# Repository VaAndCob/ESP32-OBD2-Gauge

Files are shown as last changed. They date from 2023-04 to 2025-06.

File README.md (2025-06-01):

# ESP32-OBD2-Gauge
A fully functional code-updated
Last Update: September 27th, 2024

This is an ESP32 OBD2 Gauge for vehicles that are compatible with obd2
(Special made for FORD vehicle)
 - Prototype https://youtu.be/PkQaUJbzTNM
 - Current Model Short Demo https://youtu.be/vvBIeim7XTE
   
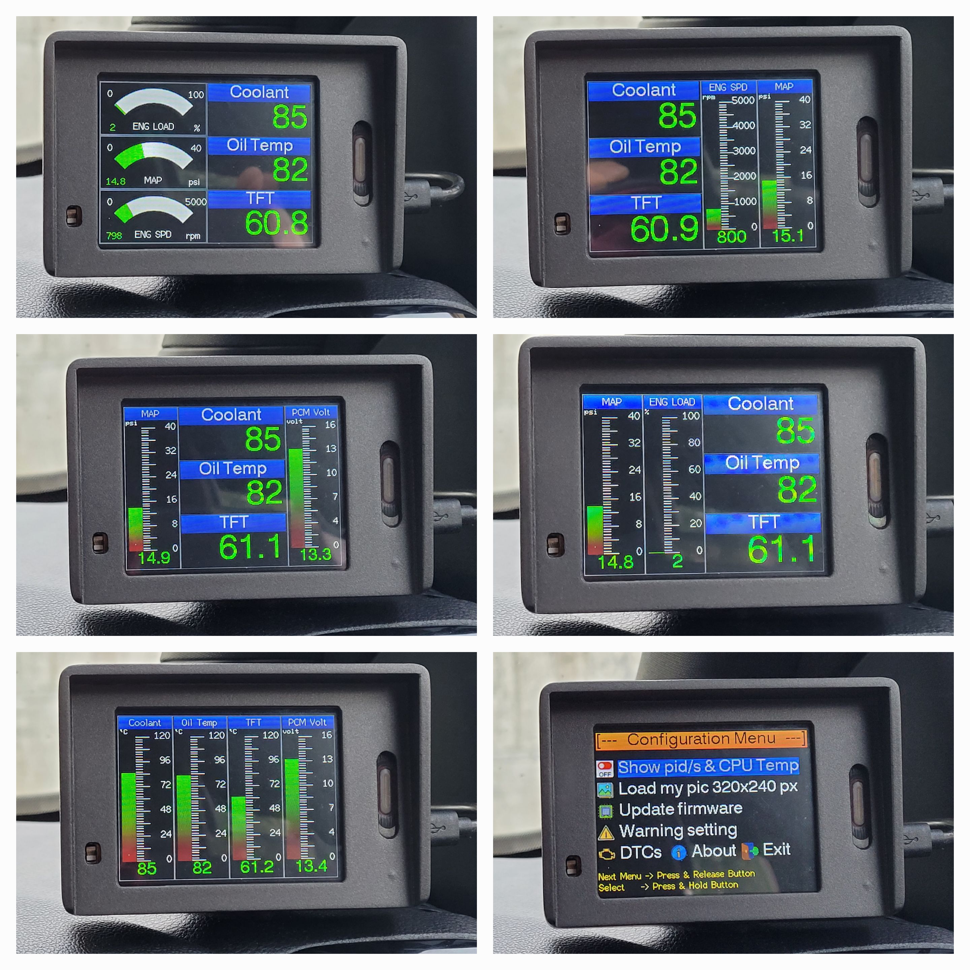
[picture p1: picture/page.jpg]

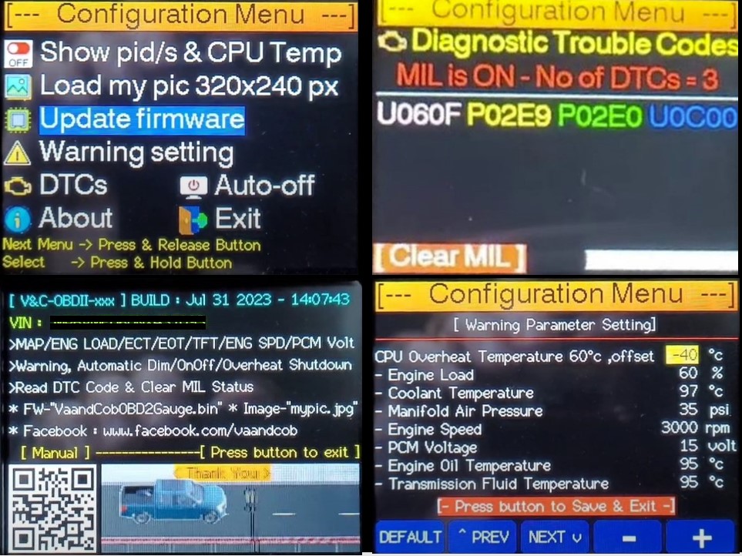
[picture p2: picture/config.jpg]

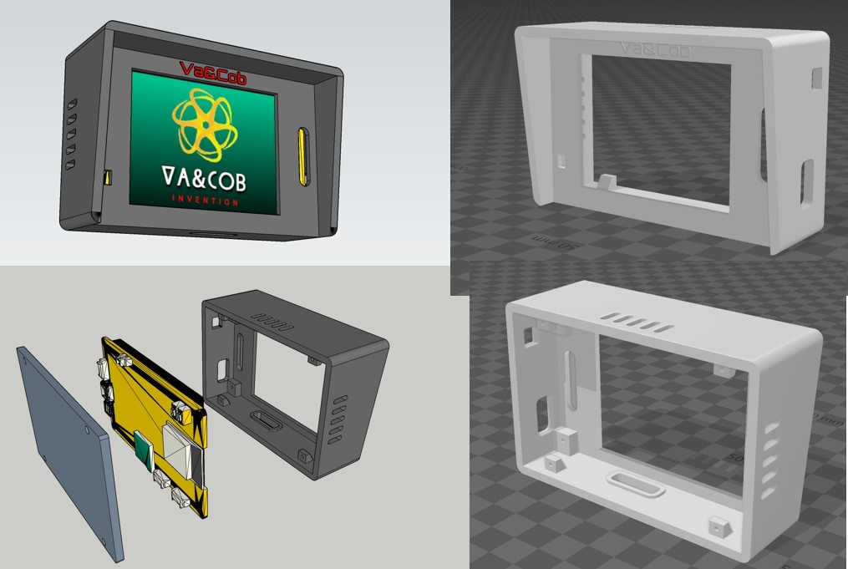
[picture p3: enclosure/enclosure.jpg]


## Software:
- Arduino IDE 2.3.2 + ESP32 arduino core 2.0.17
- * IMPORTANT * this project won't work with ESP32 arduiino core 3.x.x
- modified TFT_eSPI library 2.5.43

## Hardware
- ESP32 TFT2.8 320x240 with "RESISTIVE" touch board.
buy here  https://s.click.aliexpress.com/e/_Ew95gMl 
- ELM327 Bluetooth adaptor (recommended v1.5 not v2.1)
  Highly recommend ELM327 Bluetooth  adaptor https://s.click.aliexpress.com/e/_oo3THvG
- A small speaker for mobile phone 1 Watt 8 ohm 9x28 mmm.
- A push button 6x6x5 2 legs
- 3d print enclosure
- 12v to 5v dc micro usb power regulator module
- Gauge magnetic stand

## Features:
- Show vehicle data 7 pids
* MAP - manifold air pressure (PSI)
* PCM - pcm voltage (volt)
* ENG LOAD - engine load (%)
* ENG SPD - engine speed (RPM)
* Coolant - coolant temperature (c)
* Oil Temp - engine oil temperature (c)
* TFT - Ford transmission fluid temperature (c)

- 8 layout page selectable display
- DTC read and clear function (Engine warning light only)
- Warning when parameter reaches setting value
- Adjustable warning value for each PIDs
- Configurable CPU overheat protection
- Configurable gauge Auto turn on/off
- Auto screen brightness
- Change off screen to user screen with micro SDcard
- Firmware updatable (micro SDcard and WiFi)
- VIN Read on the About page.

## [Flash Firmware Online](https://vaandcob.github.io/webpage/src/index.html)

-------------------------------------------------------
Buy Me a Coffee (https://www.buymeacoffee.com/vaandcob)

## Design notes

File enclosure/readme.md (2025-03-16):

3d print files



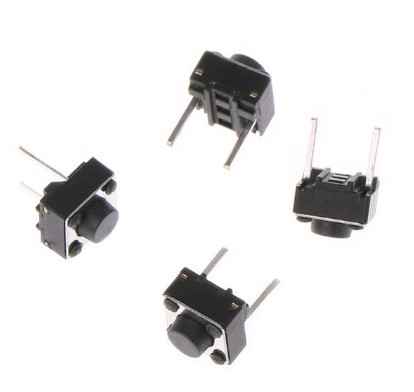
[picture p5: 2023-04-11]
hardware/push_button.jpg

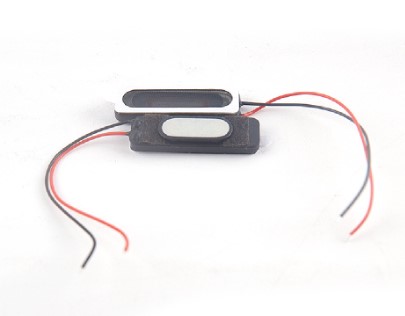
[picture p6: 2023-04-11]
hardware/speaker.jpg

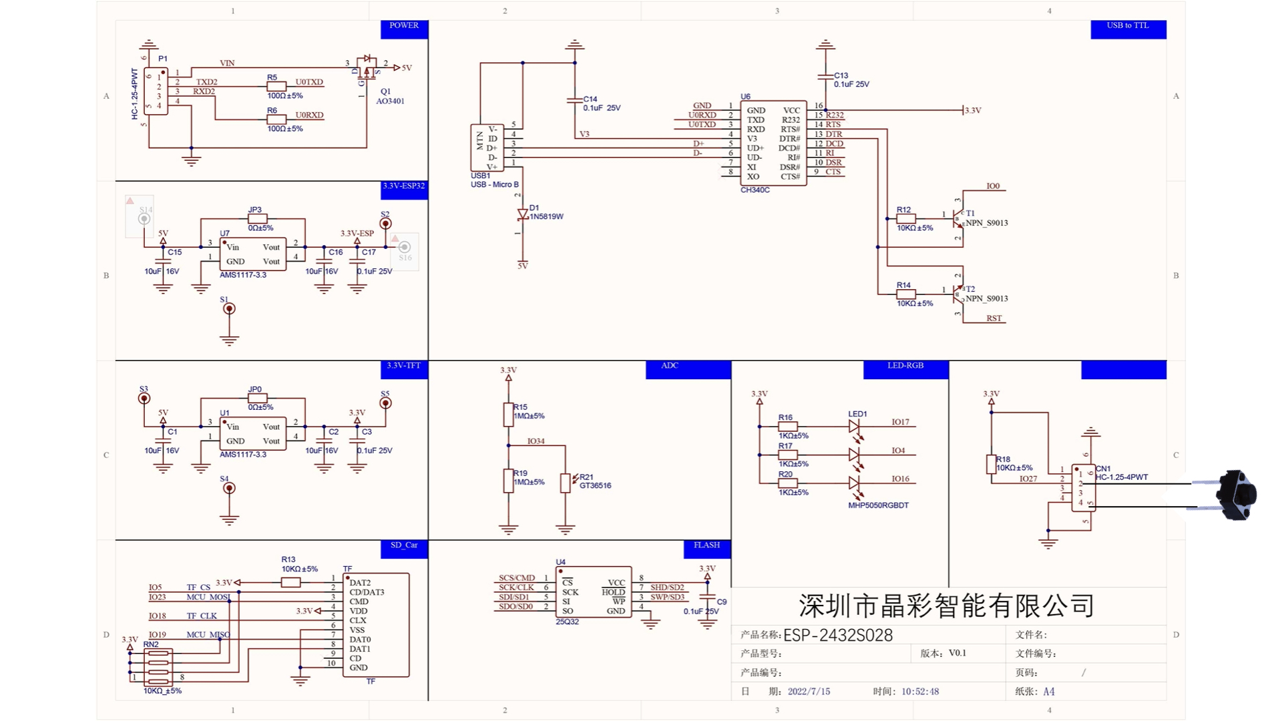
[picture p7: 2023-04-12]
hardware/ESP32-2432S028-LCM002.jpeg

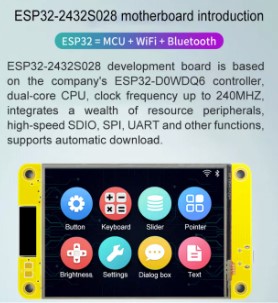
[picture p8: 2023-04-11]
hardware/ESP32 lvgl_touch.jpg

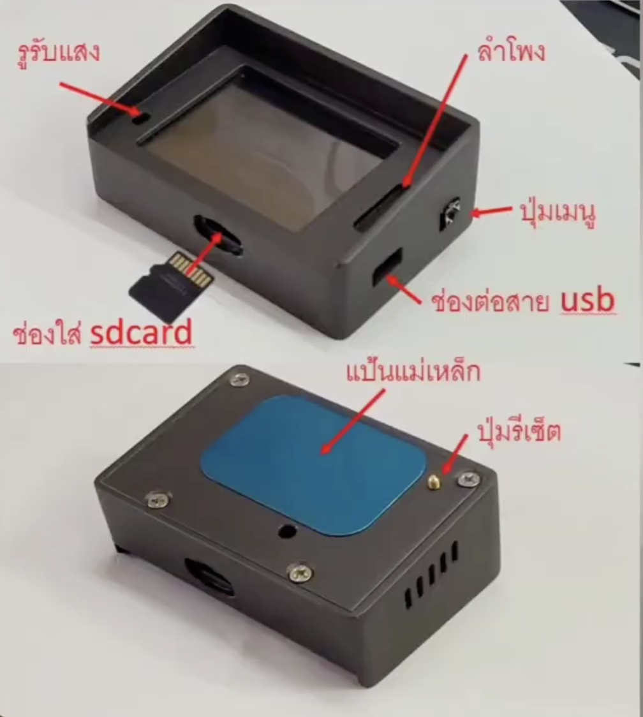
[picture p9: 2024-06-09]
hardware/Box.png

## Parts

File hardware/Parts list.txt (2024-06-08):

ESP32 Arduino LVGL WIFI&Bluetooth Development Board 2.8" 240*320 Smart Display Screen 2.8inch LCD TFT Module With Touch WROOM
https://s.click.aliexpress.com/e/_DB8Ht8N

Micro USB Output 12V to 5V 3A 
https://shopee.co.th/%E2%98%80S%E2%98%80%E0%B8%AD%E0%B8%B8%E0%B8%9B%E0%B8%81%E0%B8%A3%E0%B8%93%E0%B9%8C%E0%B9%81%E0%B8%9B%E0%B8%A5%E0%B8%87%E0%B8%9E%E0%B8%B2%E0%B8%A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

ELM327 Bluetooth
https://s.click.aliexpress.com/e/_oo3THvG

Speaker 1W 8R 2809 8ohm
https://shopee.co.th/(Takashitree)-%E0%B8%A5%E0%B9%8D%E0%B8%B2%E0%B9%82%E0%B8%9E%E0%B8%87%E0%B8%AE%E0%B8%AD%E0%B8%A3%E0%B9%8C%E0%B8%99%E0%B8%84%E0%B8%AD%E0%B8%A1%E0%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

Push button
Push Bottom Switch  6x6x5 mm

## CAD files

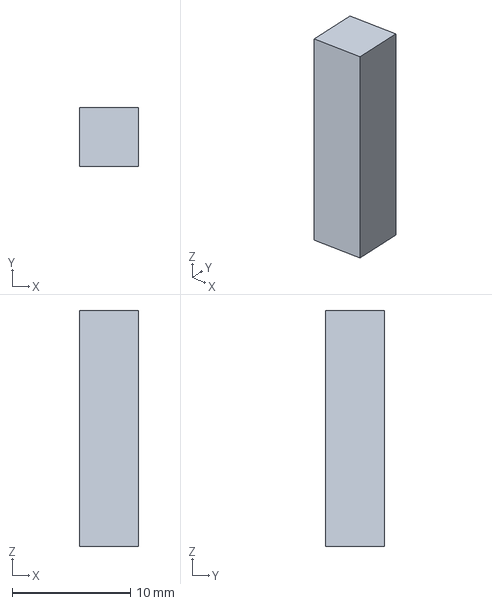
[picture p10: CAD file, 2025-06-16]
enclosure/Va&CobGauge.3mf
5.00 x 5.00 x 20.0 mm

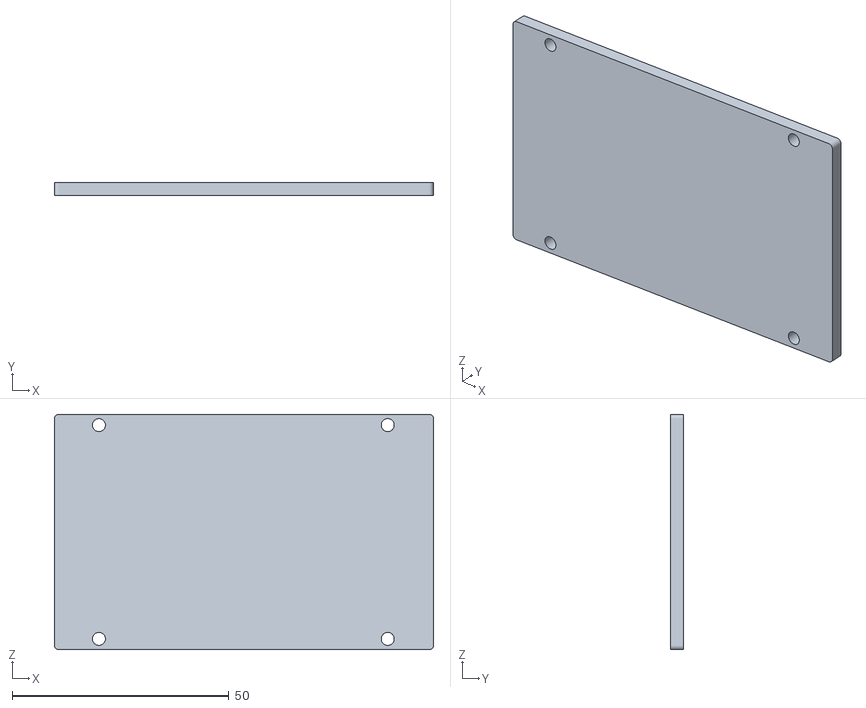
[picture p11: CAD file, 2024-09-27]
enclosure/backcover.stl
87.4 x 3.00 x 54.3

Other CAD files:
enclosure/Va&CobGauge.gcode.3mf
enclosure/Va&CobGauge.skp
enclosure/Va&CobGauge.stl

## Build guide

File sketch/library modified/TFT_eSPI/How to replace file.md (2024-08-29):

TFT_eSPI release 2.5.43

Explore to 
- C:\...\Arduino\Sketch\libraries\TFT_eSPI
- backup User_Setup.h file by rename to User_Setup_ORG.h
- copy new User_Setup.h to TFT_eSPI folder

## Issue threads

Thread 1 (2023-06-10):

Instructions how to use

nomidaepapi, 2023-06-10:
Hello. Im tryping to make a OBD2 project with my Lexus GS300 2001 with a ESP32 and ELM327 bluetooth adapter 2.1. I want to use your lib to connect to the ELM327 and retrieve RPM values; but which code do i use exactly to do this?

VaAndCob, 2023-06-11:
In the sketch. There are 4-5 sketches that run together for this project.
In case you want to read rpm or etc..
It's all about interpretation with elm327.
I suggest you read more info about elm327 at command.
Or you can simply try elm327 bluetooth with Bluetooth terminal app and see how it responds.
If possible, i suggest you test your elm327 2.1 via obd2 app on store and see if your adapter is really compatible or works with your lexus car

Closed 2024-05-09.

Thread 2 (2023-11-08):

Incompatibility with BluetoothSerial library on LilyGo T-Display-S3

Talha-Babar, 2023-11-08:
i am working on similar project and when i attempting to use the BluetoothSerial library with the LilyGo T-Display-S3 board results in compilation errors. The same code compiles and runs as expected on a standard ESP32 board, indicating the issue is specific to the LilyGo T-Display-S3 board.

Here is the code:

#include "BluetoothSerial.h"

BluetoothSerial SerialBT; // Object for Bluetooth

void setup() {
Serial.begin(115200); // Start the built-in serial port, possibly to communicate with the host computer
//SerialBT.begin("ESP32test"); // Start BluetoothSerial with the name "ESP32test"

Serial.println("Bluetooth device is ready to pair");
}

void loop() {
if (SerialBT.available()) { // Check if we receive anything from Bluetooth
Serial.write(SerialBT.read()); // Send what we receive to the built-in serial port
}

if (Serial.available()) { // Check if anything is coming from the built-in serial port
SerialBT.write(Serial.read()); // Send what we receive to Bluetooth
}
}

Here is the error:

c:/users/talha/appdata/local/arduino15/packages/esp32/tools/xtensa-esp32s3-elf-gcc/esp-2021r2-patch5-8.4.0/bin/../lib/gcc/xtensa-esp32s3-elf/8.4.0/../../../../xtensa-esp32s3-elf/bin/ld.exe: libraries\BluetoothSerial\BluetoothSerial.cpp.o:(.literal._ZL8_stop_btv+0x18): undefined reference to esp_spp_disconnect' c:/users/talha/appdata/local/arduino15/packages/esp32/tools/xtensa-esp32s3-elf-gcc/esp-2021r2-patch5-8.4.0/bin/../lib/gcc/xtensa-esp32s3-elf/8.4.0/../../../../xtensa-esp32s3-elf/bin/ld.exe: libraries\BluetoothSerial\BluetoothSerial.cpp.o:(.literal._ZL8_stop_btv+0x1c): undefined reference to esp_spp_deinit'
c:/users/talha/appdata/local/arduino15/packages/esp32/tools/xtensa-esp32s3-elf-gcc/esp-2021r2-patch5-8.4.0/bin/../lib/gcc/xtensa-esp32s3-elf/8.4.0/../../../../xtensa-esp32s3-elf/bin/ld.exe: libraries\BluetoothSerial\BluetoothSerial.cpp.o: in function _stop_bt()': C:\Users\Talha\AppData\Local\Arduino15\packages\esp32\hardware\esp32\2.0.14\libraries\BluetoothSerial\src/BluetoothSerial.cpp:714: undefined reference to esp_spp_disconnect'
c:/users/talha/appdata/local/arduino15/packages/esp32/tools/xtensa-esp32s3-elf-gcc/esp-2021r2-patch5-8.4.0/bin/../lib/gcc/xtensa-esp32s3-elf/8.4.0/../../../../xtensa-esp32s3-elf/bin/ld.exe: C:\Users\Talha\AppData\Local\Arduino15\packages\esp32\hardware\esp32\2.0.14\libraries\BluetoothSerial\src/BluetoothSerial.cpp:715: undefined reference to `esp_spp_deinit'
collect2.exe: error: ld returned 1 exit status
exit status 1
Error compiling for board LilyGo T-Display-S3.

VaAndCob, 2023-11-09:
my sketch used the esp32 core library,  [BluetoothSerial.h](https://github.com/espressif/arduino-esp32/tree/master/libraries/BluetoothSerial)
Not the library from external source
or if you use arduino-esp32 BluetoothSerial.h   ,  perhaps it doesn't update and not compatible with Lilygi ESP32 S3,
but you can edit this library.  Those errors are  "undefined references"

Closed 2024-05-09.

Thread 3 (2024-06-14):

i dont have the yellow display..but i have the 2.4inch spi interface display..

rohanjoshy2005, 2024-06-14:
i dont have the yellow display..but i have the 2.4inch spi interface display...is this display compaitable with this project and can you give me the wiring digram

VaAndCob, 2024-06-16:
This module tft screen use SPI as well. For the schematic diagram, it's in hardware folder.

VaAndCob, 2024-06-16:
This module tft screen use SPI as well. For the schematic diagram, it's in hardware folder.

rohanjoshy2005, 2024-06-16:
and i have the basic version of obd2..ELM327 mini...is it possible to do with it

VaAndCob, 2024-08-02:
> and i have the basic version of obd2..ELM327 mini...is it possible to do with it

you can try, nobody can say, but I recommend original ELM327 with pic chip.

rohanjoshy2005, 2024-08-04:
can you please give me the pinout for each components(not like diagram)like
vcc-3v,gnd-gnd like that

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

VaAndCob, 2024-08-05:
> can you please give me the pinout for each components(not like diagram)like vcc-3v,gnd-gnd like that
> […](#)

you can google ESP32 and TFT 2.4" SPI example , connection, diagram and example code.

Closed 2024-10-09.

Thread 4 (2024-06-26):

Question: Enclosure design files

aguedob, 2024-06-26:
First of all, congrats for such a great project! I have one question for you. I really like the enclosure shown in your photos. Is 3d printed? Do you have the design files? Thank you!

mateusleom, 2024-09-20:
[Case Esp32.zip](https://github.com/user-attachments/files/17074926/Case.Esp32.zip)
I made this myself, its similar to the one shown in the developer pictures

VaAndCob, 2024-09-27:
> [Case Esp32.zip](https://github.com/user-attachments/files/17074926/Case.Esp32.zip) I made this myself, its similar to the one shown in the developer pictures

thank you mateusteom. very appreciated

VaAndCob, 2024-09-27:
> First of all, congrats for such a great project! I have one question for you. I really like the enclosure shown in your photos. Is 3d printed? Do you have the design files? Thank you!

I upload 3d print file for this enclosure, you can see it in 'enclosure folder'

Closed 2024-10-09.

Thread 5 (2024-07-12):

Please elaborate on "New device must flash "gauge_factory_init.ino" first to get it work by checking 'serialno' in pref."

rlagerweij, 2024-07-12:
I'm trying to flash your project to my new device. It is identical to the one you linked to. After building and flashing i just get a black screen and the text "Touch screen calibration..." on the serial monitor.

You mention in the notes: "New device must flash "gauge_factory_init.ino" first to get it work by checking 'serialno' in pref."

Is this related to the issue I am having?

I do not see this particular file in the source tree and google cant find it either.
Could you explain where I can find this file and what it does to the board to prepare it for you firmware?

Many thanks

VaAndCob, 2024-07-15:
you can skip this part in vaandcobobd2gauge.ino

remove guine check line. to skip checking.

ในวันที่ ศ. 12 ก.ค. 2024 เวลา 22:30 rlagerweij ***@***.***>
เขียนว่า:

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

--

*:•°ღ ♡♥♡♥♡♥♡♥♡ ღ*:•°*:•°ღ ♡♥♡♥♡♥♡♥♡ ღ*:•°

ks00x, 2024-07-16:
> I'm trying to flash your project to my new device. It is identical to the one you linked to. After building and flashing i just get a black screen and the text "Touch screen calibration..." on the serial monitor.

What you are seeing is the touchscreen calibration screen which only comes up the first time after the flash was erased. You need to click the 4 corners following the arrows and then the cal data is saved to flash. I have the thing running now but it is not connecting to my ODB adapters. I guess it needs the mac addr or id string first to work and maybe this is what the gauge_factory_init.ino is supposed to do...

rlagerweij, 2024-07-16:
The problem was that the screen remained off during the calibration stage.

I got it working by first applying the user_config.h to the eSPI_TFT library and then loading the device with an example from the library. After that i removed the calibration step from Setup() and then the logo showed up.

Can't really say what exactly fixed it.

VaAndCob, 2024-08-02:
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

example from TFT_espi might not work with this board. that's why I build 'touch.h' to use with this board.
Can u try compile sketch and run.  or if you could flash binary file to your board. (I have provided binary file)

Closed 2024-10-09.

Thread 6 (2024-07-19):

error: 'sigmaDeltaSetup' was not declared in this scope

amirzohaib, 2024-07-19:
error: 'sigmaDeltaSetup' was not declared in this scope

in the nes_audio.cpp. maybe its a library i need to install?

amirzohaib, 2024-07-19:
C:\Users\c9002481\Documents\Platform IO\ESP32-OBD2-Gauge-main\nes_audio.cpp: In member function 'void Cartridge::init()':
C:\Users\c9002481\Documents\Platform IO\ESP32-OBD2-Gauge-main\nes_audio.cpp:17:3: error: 'sigmaDeltaSetup' was not declared in this scope; did you mean 'sigmaDeltaDetach'?
   17 |   sigmaDeltaSetup(p1_pin, p1_channel, 88200);
      |   ^~~~~~~~~~~~~~~
      |   sigmaDeltaDetach
In file included from C:\Users\c9002481\Documents\Platform IO\ESP32-OBD2-Gauge-main\ESP32-OBD2-Gauge-main.ino:258:
C:\Users\c9002481\Documents\Platform IO\ESP32-OBD2-Gauge-main\config.h: In function 'void TaskPlayMusic(void*)':
C:\Users\c9002481\Documents\Platform IO\ESP32-OBD2-Gauge-main\config.h:58:21: error: invalid conversion from 'int' to 'const esp_task_wdt_config_t*' [-fpermissive]
   58 |   esp_task_wdt_init(62, false);//62 sec wd timer / disable wd
      |                     ^~
      |                     |
      |                     int
C:\Users\c9002481\Documents\Platform IO\ESP32-OBD2-Gauge-main\config.h:58:20: error: too many arguments to function 'esp_err_t esp_task_wdt_init(const esp_task_wdt_config_t*)'
   58 |   esp_task_wdt_init(62, false);//62 sec wd timer / disable wd
      |   ~~~~~~~~~~~~~~~~~^~~~~~~~~~~
In file included from C:\Users\c9002481\Documents\Platform IO\ESP32-OBD2-Gauge-main\config.h:5:
C:\Users\c9002481\AppData\Local\Arduino15\packages\esp32\tools\esp32-arduino-libs\idf-release_v5.1-bd2b9390ef\esp32/include/esp_system/include/esp_task_wdt.h:47:11: note: declared here
   47 | esp_err_t esp_task_wdt_init(const esp_task_wdt_config_t *config);
      |           ^~~~~~~~~~~~~~~~~
C:\Users\c9002481\Documents\Platform IO\ESP32-OBD2-Gauge-main\config.h: In function 'void configMenu()':
C:\Users\c9002481\Documents\Platform IO\ESP32-OBD2-Gauge-main\config.h:715:13: error: 'ledcAttachPin' was not declared in this scope; did you mean 'ledcAttach'?
  715 |             ledcAttachPin(BUZZER_PIN, buzzerChannel);//reattach buzzer pin
      |             ^~~~~~~~~~~~~
      |             ledcAttach
C:\Users\c9002481\Documents\Platform IO\ESP32-OBD2-Gauge-main\ESP32-OBD2-Gauge-main.ino: In function 'void setup()':
C:\Users\c9002481\Documents\Platform IO\ESP32-OBD2-Gauge-main\ESP32-OBD2-Gauge-main.ino:274:3: error: 'ledcSetup' was not declared in this scope
  274 |   ledcSetup(buzzerChannel, 1500, 10);//buzzer 10 bit
      |   ^~~~~~~~~
C:\Users\c9002481\Documents\Platform IO\ESP32-OBD2-Gauge-main\ESP32-OBD2-Gauge-main.ino:276:3: error: 'ledcAttachPin' was not declared in this scope; did you mean 'ledcAttach'?
  276 |   ledcAttachPin(BUZZER_PIN, buzzerChannel);//attach buzzer
      |   ^~~~~~~~~~~~~
      |   ledcAttach
Multiple libraries were found for "SD.h"
  Used: C:\Users\c9002481\AppData\Local\Arduino15\packages\esp32\hardware\esp32\3.0.2\libraries\SD
  Not used: C:\Users\c9002481\AppData\Local\Arduino15\libraries\SD
exit status 1

Compilation error: 'sigmaDeltaSetup' was not declared in this scope; did you mean 'sigmaDeltaDetach'?

VaAndCob, 2024-08-02:
please check if you use  ESP32 Arduino core 2.0.7,  it's not compatible with new COre 3.xx

VaAndCob, 2024-08-02:
> C:\Users\c9002481\Documents\Platform IO\ESP32-OBD2-Gauge-main\nes_audio.cpp: In member function 'void Cartridge::init()': C:\Users\c9002481\Documents\Platform IO\ESP32-OBD2-Gauge-main\nes_audio.cpp:17:3: error: 'sigmaDeltaSetup' was not declared in this scope; did you mean 'sigmaDeltaDetach'? 17 | sigmaDeltaSetup(p1_pin, p1_channel, 88200); | ^~~~~~~~~~~~~~~ | sigmaDeltaDetach In file included from C:\Users\c9002481\Documents\Platform IO\ESP32-OBD2-Gauge-main\ESP32-OBD2-Gauge-main.ino:258: C:\Users\c9002481\Documents\Platform IO\ESP32-OBD2-Gauge-main\config.h: In function 'void TaskPlayMusic(void*)': C:\Users\c9002481\Documents\Platform IO\ESP32-OBD2-Gauge-main\config.h:58:21: error: invalid conversion from 'int' to 'const esp_task_wdt_config_t*' [-fpermissive] 58 | esp_task_wdt_init(62, false);//62 sec wd timer / disable wd | ^~ | | | int C:\Users\c9002481\Documents\Platform IO\ESP32-OBD2-Gauge-main\config.h:58:20: error: too many arguments to function 'esp_err_t esp_task_wdt_init(const esp_task_wdt_config_t*)' 58 | esp_task_wdt_init(62, false);//62 sec wd timer / disable wd | ~~~~~~~~~~~~~~~~~^~~~~~~~~~~ In file included from C:\Users\c9002481\Documents\Platform IO\ESP32-OBD2-Gauge-main\config.h:5: C:\Users\c9002481\AppData\Local\Arduino15\packages\esp32\tools\esp32-arduino-libs\idf-release_v5.1-bd2b9390ef\esp32/include/esp_system/include/esp_task_wdt.h:47:11: note: declared here 47 | esp_err_t esp_task_wdt_init(const esp_task_wdt_config_t *config); | ^~~~~~~~~~~~~~~~~ C:\Users\c9002481\Documents\Platform IO\ESP32-OBD2-Gauge-main\config.h: In function 'void configMenu()': C:\Users\c9002481\Documents\Platform IO\ESP32-OBD2-Gauge-main\config.h:715:13: error: 'ledcAttachPin' was not declared in this scope; did you mean 'ledcAttach'? 715 | ledcAttachPin(BUZZER_PIN, buzzerChannel);//reattach buzzer pin | ^~~~~~~~~~~~~ | ledcAttach C:\Users\c9002481\Documents\Platform IO\ESP32-OBD2-Gauge-main\ESP32-OBD2-Gauge-main.ino: In function 'void setup()': C:\Users\c9002481\Documents\Platform IO\ESP32-OBD2-Gauge-main\ESP32-OBD2-Gauge-main.ino:274:3: error: 'ledcSetup' was not declared in this scope 274 | ledcSetup(buzzerChannel, 1500, 10);//buzzer 10 bit | ^~~~~~~~~ C:\Users\c9002481\Documents\Platform IO\ESP32-OBD2-Gauge-main\ESP32-OBD2-Gauge-main.ino:276:3: error: 'ledcAttachPin' was not declared in this scope; did you mean 'ledcAttach'? 276 | ledcAttachPin(BUZZER_PIN, buzzerChannel);//attach buzzer | ^~~~~~~~~~~~~ | ledcAttach Multiple libraries were found for "SD.h" Used: C:\Users\c9002481\AppData\Local\Arduino15\packages\esp32\hardware\esp32\3.0.2\libraries\SD Not used: C:\Users\c9002481\AppData\Local\Arduino15\libraries\SD exit status 1
>
> Compilation error: 'sigmaDeltaSetup' was not declared in this scope; did you mean 'sigmaDeltaDetach'?

please check if your arduino  esp32 cord is version 2.0.17,  not 3.0.x
a new core update incompatible with some libraries.

GerryGit, 2025-04-04:
Core 2.0.17 no longer exists. It was replaced with Core 2.0.18. When buidlng with core 2.0.18 this bug still exists.

VaAndCob, 2025-04-06:
> Core 2.0.17 no longer exists. It was replaced with Core 2.0.18. When buidlng with core 2.0.18 this bug still exists.

Actually you can select to install 2.0.17.  Whatis the bug or error report?

GerryGit, 2025-04-06:
Thanks, I did find and install 2.0.17 and could build with no errors.

Closed 2024-10-09.

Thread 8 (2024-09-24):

stuck with compilation

pacraf, 2024-09-24:
What can be the reason of this error
C:\Users\Uzytkownik\Documents\Arduino\VaAndCobOBD2Gauge\VaAndCobOBD2Gauge.ino: In function 'void setup()':
C:\Users\Uzytkownik\Documents\Arduino\VaAndCobOBD2Gauge\VaAndCobOBD2Gauge.ino:307:3: error: 'touchscreenSPI' was not declared in this scope
   touchscreenSPI.begin(XPT2046_CLK, XPT2046_MISO, XPT2046_MOSI, XPT2046_CS);
   ^~~~~~~~~~~~~~

I installed library
XPT2046_Touchscreen  version 1.4
TFT_eSPI 2.5.43 , and replaced User_Setup.h accordingly
JPEGDecoder 2.0.0
idf core (boards) is on version 2.0.17

what I am doing wrong, that the compilation stucks on that? I see that libraries are "seen" because when removed, I have instant error about missing libraries

***** EDIT
having no other ideas, I just found that someone forked this project two months ago, so I grabbed this version and it compiles...
so something happened in last two months. that one compiled and works when loaded to board. I did not yet tested with ELM , but so far so good.

VaAndCob, 2024-09-27:
HI, I upload a new files on github , please re download again, I guess it's
missing updated files

ในวันที่ อ. 24 ก.ย. 2024 เวลา 14:38 pacraf ***@***.***>
เขียนว่า:

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

--

*:•°ღ ♡♥♡♥♡♥♡♥♡ ღ*:•°*:•°ღ ♡♥♡♥♡♥♡♥♡ ღ*:•°

paulos2, 2024-09-28:
thx i waiting for it

Closed 2024-10-09.

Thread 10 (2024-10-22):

Board crashing after connection when attempting to add new hybrid focused PIDs

cr08, 2024-10-22:
Hi! Hope I can get some direction and pointers. I've exhausted the debugging options I can some up with on this. My Arduino/ESP32 knowledge is fairly limited.

But I'm trying to modify this and add some hybrid specific PIDs from my own Ford vehicle. The stock code works fine and the various gauges show data where available. However once I add the new PID (just doing one for now to test) once the connection is established and the first display page is rendered it crashes.

Here's the manual queries I ran on my OBD adapter:
```
>001100BB

41 0B 63

>00110055                                                                                                
                                                                                                         
41 05 34                                                                                                 
41 05 34                                                                                                 
41 05 34                                                                                                 
                                                                                                         
>00110044                                                                                                
                                                                                                         
41 04 00                                                                                                 
41 04 00                                                                                                 
41 04 00                                                                                                 
                                                                                                         
>001155cc                                                                                                
                                                                                                         
NO DATA                                                                                                  
                                                                                                         
>222211667744                                                                                            
                                                                                                         
NO DATA                                                                                                  

>222211ee11cc

62 1E 1C 00 C3
62 1E 1C 00 F8

>222244880011

62 48 01 BA EB

>2222dddd0044

62 DD 04 FF
62 DD 04 38

>2222448800bb

62 48 0B 00 00
62 48 0B 00 00

>222244884411

62 48 41 0F CD
```

Ignore the duplicate characters. I misconfigured my minicom instance. But PID 224801 is the one I tested with in the sketch. PIDs 22480B, 22DD04, and 224841 are additional ones I want to use but haven't put into the sketch yet. I'm testing with the one for now.

Here's the serial monitor log:
```

<<  Va&Cob OBDII Gauge  >>
by Ratthanin W. BUILD -> Oct 20 2024 - 15:56:55
Error: File not found!
Show System: 0
Temp Offset: -50
Bluetooth..OK
Connecting to OBDII - 00:1d:a5:00:02:40
Connected Successfully!
ATZ

ELM327 v1.5

Display layout -> 0
010B
41 0B 63

010C
41 0C 00 00
41 0C 00 00
41 0C 00 00

Guru Meditation Error: Core  1 panic'ed (StoreProhibited). Exception was unhandled.

Core  1 register dump:
PC      : 0x40092728  PS      : 0x00060a30  A0      : 0x800ef26f  A1      : 0x3ffd08a0
A2      : 0xae5b725a  A3      : 0x3ffd098c  A4      : 0x00000003  A5      : 0x0000ff00
A6      : 0x00ff0000  A7      : 0xff000000  A8      : 0x00000000  A9      : 0xae5b725a
A10     : 0x00000030  A11     : 0x00000000  A12     : 0x00000001  A13     : 0x0000ff00
A14     : 0x00ff0000  A15     : 0xff000000  SAR     : 0x00000015  EXCCAUSE: 0x0000001d
EXCVADDR: 0xae5b725a  LBEG    : 0x4009273c  LEND    : 0x40092741  LCOUNT  : 0x00000000

Backtrace: 0x40092725:0x3ffd08a0 0x400ef26c:0x3ffd08c0 0x400ef38a:0x3ffd08e0 0x400d54ca:0x3ffd0900 0x400dae52:0x3ffd09c0 0x400f24dd:0x3ffd0a40
```

Ran an exception decoder:
```
Backtrace: 0x40092725:0x3ffd08a0 0x400ef26c:0x3ffd08c0 0x400ef38a:0x3ffd08e0 0x400d54ca:0x3ffd0900 0x400dae52:0x3ffd09c0 0x400f24dd:0x3ffd0a40

Decoding stack results
0x40092725: memmove at /builds/idf/crosstool-NG/.build/xtensa-esp32-elf/src/newlib/newlib/libc/string/memmove.c:75
0x400ef26c: String::move(String&) at /home/cr08/.arduino15/packages/esp32/hardware/esp32/2.0.17/cores/esp32/WString.cpp:237
0x400ef38a: String::operator=(String&&) at /home/cr08/.arduino15/packages/esp32/hardware/esp32/2.0.17/cores/esp32/WString.cpp:277
0x400d54ca: getAB(String) at /home/cr08/Software/ESP32-OBD2-Gauge_cr08/sketch/VaAndCobOBD2Gauge/meter.h:396
0x400dae52: loop() at /home/cr08/Software/ESP32-OBD2-Gauge_cr08/sketch/VaAndCobOBD2Gauge/VaAndCobOBD2Gauge.ino:480
0x400f24dd: loopTask(void*) at /home/cr08/.arduino15/packages/esp32/hardware/esp32/2.0.17/cores/esp32/main.cpp:50
```

Since I have my own fork for this with some added lines, here should be direct links to the lines being referenced:
https://github.com/cr08/ESP32-OBD2-Gauge/blob/cd845ff29f4046cf22e46fbfb5648ac8caeb7632/sketch/VaAndCobOBD2Gauge/VaAndCobOBD2Gauge.ino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

https://github.com/cr08/ESP32-OBD2-Gauge/blob/cd845ff29f4046cf22e46fbfb5648ac8caeb7632/sketch/VaAndCobOBD2Gauge/meter.h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

Added the PID as an extra line which should come up as PID number 7 and that's been added in display 0:
https://github.com/cr08/ESP32-OBD2-Gauge/blob/cd845ff29f4046cf22e46fbfb5648ac8caeb7632/sketch/VaAndCobOBD2Gauge/VaAndCobOBD2Gauge.ino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

And also an extra formula line for it:
https://github.com/cr08/ESP32-OBD2-Gauge/blob/cd845ff29f4046cf22e46fbfb5648ac8caeb7632/sketch/VaAndCobOBD2Gauge/meter.h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

Probably a lot of info but wanted to make sure I provide as much as I can and what I've ran through trying to debug it myself. Any help would be greatly appreciated in trying to figure this out. Seems I'm so close to getting it going.

Thanks!

VaAndCob, 2024-10-23:
Seem esp32 crashed by something about wrong code operation or memory.
Please recheck if you set the correct board (ESP32 Devkit) and parttion
(minimum spiffs OTA)

I'll review your fork again.

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

VaAndCob, 2024-10-23:
oh one more thing. some ELM327 adaptors are low quality.  slow speed and sometimes return garbage data, since the code itself, there is no error checking. this could lead to error during calculation.

cr08, 2024-10-26:
Thanks for looking into it! Yeah, I'm very aware of some adapter's quality. I've had a few over the years that have been hit or miss. This one I'm working with I have had before I discovered this project but specifically picked out because it had the recommended PIC18F25K80 chip and separate bluetooth daughterboard which seems to be better amongst the clones out there and should be the same as the linked Aliexpress product aside from being a different brand.

I did do some further testing. First thing I did was run the 'SerialToSerialBTM' example code from the Arduino IDE which basically allows a simple Bluetooth to serial monitor terminal so I could manually run things from the same board for debugging. Followed all the init commands in your code and then tried to poll the PIDs. All looks good to me?

```
ATE0
OK

>SEARCHING...
41 00 00 00 00 00
41 00 98 18 00 13
41 00 BE 3F A8 13
41 00 98 18 00 13
STOPPED

>41 05 39
41 05 39
41 05 39
STOPPED

>62 48 01 BA 18
STOPPED

>41 0C 00 00
41 0C 00 00
STOPPED

>62 48 0B FF F6
62 48 0B 00 00
STOPPED

>62 48 01 BA 11
STOPPED
```

The `62 48 01 XX XX` is the PID I've been working on once again.

I did also try adjusting the formula for that PID to clean it up some and more closely match some of the other formula in case that was an issue. The math still checks out:

```
case 7: data = (A*256+B)/5/100; break;
```

Unfortunately still have the same issue.

VaAndCob, 2024-10-27:
From the response
>62 48 01 BA 11
STOPPED
it gave "STOPPED" or  nothing I'm not sure about the ELM327 adaptor you use,
but the code from here
https://github.com/cr08/ESP32-OBD2-Gauge/blob/cd845ff29f4046cf22e46fbfb5648ac8caeb7632/sketch/VaAndCobOBD2Gauge/meter.h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

at line 378
```
//get A B from response return in global A B variable
void getAB(String elm_rsp) {  //41 05 2A 3C 01>
  if (elm_rsp == "NO DATA\r\r>") {//pid no data
    A = 0;
    B = 0;
```
this block is about to check if no data for that pid (returned from ELM327 adaptor)  then give A and B = 0

but your response might be "STOPPED"  or something else (empty, null, etc, including \r\n or not)  this make code interpret wrong A and B  and calculate , which could lead to crash.

Can u exactly check what your ELM327 adaptor really response the command  224801?
as I said,  it might be "STOPPED" , NULL , or just newline linefeed \r\n

VaAndCob, 2024-10-27:
BTW, you can try edit this block,  to handle no data return but "STOPPED" return
```
void getAB(String elm_rsp) {  //41 05 2A 3C 01>
  if (elm_rsp == "STOPPED\r\r>") {//pid no data
    A = 0;
    B = 0;
```

VaAndCob, 2024-10-27:
https://wokwi.com/projects/412905386300120065

I test the code, it works without problem.  so can u debug step by step?
1. Serial.println( A and B)  after calling getAB() function.  to know exactly the value of A and B
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
VaAndCob, 2024-11-04:
I notice from the response
010B
41 0B 62

010B
41 0B 63

010B
41 0B 63

010B
CAN ERROR

Display layout -> 1
0104
41 04 00
41 04 00
41 04 00

//----------------------------------

it's like repeatedly reading 010B but sometimes the adaptor gives CAN ERROR  or
0104 adaptor returned 41 04 00 for 3 times.

this is my guess,  it could be ELM327 adaptor that return data that make esp32 crash.
so I have some few way to clarify the cause.

1. try compiled firmware
I'd like you to try this firmware.
https://github.com/VaAndCob/ESP32-OBD2-Gauge/blob/main/sketch/firmware/VaAndCobOBD2Gauge_T6_nogenuine.bin

it proved that it works (no compiling needed),  with this firmware, you can read a few simple PIDs so if you are still facing the crashing problem.  It'd be the vehicle or ELM327 adaptor.

2. Test on another car
if possible, I'd like you to try your ELM327 adaptor with your firmware on another car too (recommend OBD2 Canbus compatible)
to be sure that the ELM327 adaptor works well

3. Handle error or different response from ELM327
In the original code, we handle errors with "NO DATA\r\n"  response from the adaptor, but your adaptor returns something else too (CAN ERROR or something else that I don't know (space, control characters etc..)
so you have to screen the error and let the correct response data format be calculated as "41 0x aa bb"

I hope this help.

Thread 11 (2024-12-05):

Not Config button

deardalyvn, 2024-12-05:
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
i connected GND (black)+ IO27 (yellow) but I not push config button. Please help me.

VaAndCob, 2024-12-13:
> ![photo_2024-12-05_09-29-11](https://private-user-images.githubusercontent.com/9388686/392631360-f91f4e61-e26e-44f0-8a73-b3f3f4900723.jpg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) ![photo_2024-12-05_09-29-20](https://private-user-images.githubusercontent.com/9388686/392631382-730a563f-b4ee-4b4d-a9df-bc2e2b0eaa79.jpg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) i connected GND (black)+ IO27 (yellow) but I not push config button. Please help me.

Please comment out genuinecheck line. (I stated in the source code, please read)

Closed 2025-05-20.

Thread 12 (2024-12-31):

No longer get pids

mateusleom, 2024-12-31:
I used my elm327 in another car to clear DTCs and since then, my esp32 board no longer reads pids. Is says bluetooth connected but reads no pids, i tried different elm327 adaptors and also tried re-flashing the board. Nothing seems to be working. Also tried reading info from obdii using android apps, that works, so its not the car/elm327 issue.

VaAndCob, 2025-01-11:
> I used my elm327 in another car to clear DTCs and since then, my esp32 board no longer reads pids. Is says bluetooth connected but reads no pids, i tried different elm327 adaptors and also tried re-flashing the board. Nothing seems to be working. Also tried reading info from obdii using android apps, that works, so its not the car/elm327 issue.

you mean it didn't work on another car?  or you cannot clear DTCs on another car?

Closed 2025-05-20.

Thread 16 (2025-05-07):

compiling error

moroziller, 2025-05-07:
Hello. It gives an error when compiling the sketch. What library(...ies) is missing?

C:\Users\zzz\Documents\Arduino\ESP32-OBD2-Gauge-main\sketch\VaAndCobOBD2Gauge\VaAndCobOBD2Gauge.ino:42:10: fatal error: Preferences.h: No such file or directory
   42 | #include <Preferences.h>  //save permanent data
      |          ^~~~~~~~~~~~~~~
compilation terminated.

exit status 1

Compilation error: Preferences.h: No such file or directory

VaAndCob, 2025-05-14:
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

You have to install library
Preferences.h

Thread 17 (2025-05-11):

"File Not Found" Error?

GeospatialDaryl, 2025-05-11:
Thanks for the work .  I flashed an ESP32-2432S028 with both the T5 and T6 firmwares.  The device boots, queries for the ODB2 device and then connects.  It then brings up the first UI screen, and then, after a few seconds, shows "File Not Found" and powers down.

Any advice on how to troubleshoot?

VaAndCob, 2025-05-14:
> Thanks for the work .  I flashed an ESP32-2432S028 with both the T5 and T6 firmwares.  The device boots, queries for the ODB2 device and then connects.  It then brings up the first UI screen, and then, after a few seconds, shows "File Not Found" and powers down.
>
> Any advice on how to troubleshoot?

Seem it's  the automatic turn-off feature.
The gauge by deafult will read the ecu voltage, if it's lower than 12.5 volt
It will automatically turn off within a few sec (detect that user turned engine off)
So after bluetooth connected and enter the gauage display page.
Try press & hold the config button to enter config page and set the voltage to lower
(you must add this tackle button ,can see info from schematic from this repo)
All the information is in the first page. Of this repository.

GeospatialDaryl, 2025-05-20:
@VaAndCob Thanks for your response and the re-direct to the first page.

I did a search for "file not found" in the repo and couldn't find any code or documents that referenced that string.

I appreciate your time and effort!  I'll follow up and will look at a pull to idiot-proof the documentation you have already provided.

VaAndCob, 2025-05-20:
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

FYI, the file not found message warning actually is a goodbye picture display that fades whenever the gauge switches to sleep mode (engine off). You can upload your own picture, too. This function is in one of the configuration menus. Copy your own picture onto an SD card, insert it, and use the "Load my pic" function to copy the picture to the gauge.

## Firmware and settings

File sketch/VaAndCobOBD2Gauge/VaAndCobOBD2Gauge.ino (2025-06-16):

/*=========  Va&Cob OBD2 Gauge ==========
Programmed:  by Ratthanin W.
Hardware:
- Hardware 2.8" TFT ESP32 LVGL https://www.youtube.com/watch?v=d2OXlVcRYrU
Configuration:
- Partition scheme
  Minimal SPIFFS 1.9MB APP/ 190kB SPIFFS /OTA (for OTA ,must reduce code size)

Important Note:
- New device must flash "gauge_factory_init.ino" first to get it work by checking 'serialno' in pref.
  or you can skip genuine checking by comment out line no. 338
- CPU temp read never work until Bluetooth or Wifi is connected

About opening logo image and goodbye image. 
- you can save welcome page logo into gauge by saving file name "vaandcob.jpg"  size 320x240 pixels into littleFS storage.
- you can save goodbye page image into gauge by saving file name "mypic.jpg" size 320z240 pixels into littleFS storage
* if you don't want to use it, you can comment out code line no. 320 - 322
*/

//--- FLAG SETTING ----- for debugging
//#define TERMINAL //temrinal mode (no gauge)
//#define SERIAL_DEBUG //to show data in serial port
//#define SKIP_CONNECTION //skip elm327 BT connection to view meter
//#define TEST_DTC //test DTC

//#define FORD_T5   // FOR FORD T5 uncomment this line

//Intermal temperature sensor function declaration
#ifdef __cplusplus
extern "C" {
#endif
  uint8_t temprature_sens_read();
#ifdef __cplusplus
}
#endif
uint8_t temprature_sens_read();  //declare intermal temperature sensor functio

//Macro
#define array_length(x) (sizeof(x) / sizeof(x[0]))  //macro to calculate array length

//library load
#include <Preferences.h>  //save permanent data
Preferences pref;         //create preference
#include <BluetoothSerial.h>
#include <TFT_eSPI.h>  //Hardware-specific library


//Pin configuration
#define SCA_PIN 21  //not used same pin with TFT_BL
#define SCL_PIN 22  //not used (avaialable) CAN_TX
#define ADC_PIN 35  //not used (available)  CAN_RX
#define LED_RED_PIN 4
#define LED_GREEN_PIN 16
#define LED_BLUE_PIN 17
#define LDR_PIN 34       //LDR sensor
#define BUZZER_PIN 26    //speaker
#define SELECTOR_PIN 27  //push button
// setting PWM properties
#define backlightChannel 0
#define buzzerChannel 2

//DISPLAY
TFT_eSPI tft = TFT_eSPI();
#define TFT_GREY 0x5AEB


//ELM327 init https://www.elmelectronics.com/wp-content/uploads/2016/07/ELM327DS.pdf
const uint8_t elm327InitCount = 8;
const String elm327Init[elm327InitCount] = { "ATZ", "ATBRD23", "ATSP0", "ATAT2", "ATL0", "ATH0", "ATE0", "0100" };  //agressive wait response time from ECU
//const String elm327Init[elm327InitCount] = {"ATZ","ATPP0CSV35","ATPP0CON","ATSP0","ATAT2","ATL0","ATH0","ATE0","0100"};//agressive wait response time from ECU

/*------ PIDS total 7 now -------------------
Array data -> { Label , unit, pid, fomula, min, max, ,skip, digit, warn }
label = Pid label show on meter
unit = unit for pid
pid = string pid 0104
formula = formula no to calculate 
min = lowest value
max = highest value
skip = delay reading 0 - 3; 3 = max delay read
digit = want to show digit or not
warn = default warning value
*/
const String pidConfig[7][9] = {
  //[pid][data]
  { "ENG Load", "%", "0104", "2", "0", "100", "0", "0", "80" },      //0 = 0104
  { "ECT", "`C", "0105", "1", "0", "120", "3", "0", "99" },          //1 = 0105
  { "MAP", "psi", "010B", "0", "0", "40", "0", "1", "35" },          //2 = 010B
  { "ENG SPD", "rpm", "010C", "3", "0", "5000", "0", "0", "4000" },  //3 = 010C
  { "PCM Volt", "volt", "0142", "4", "0", "16", "1", "1", "15" },    //4 = 0142
#ifdef FORD_T5
  { "IAT", "`C", "010F", "1", "0", "120", "3", "0", "99" },  //5 = 015C
#else
  { "Oil Temp", "`C", "015C", "1", "0", "120", "3", "0", "99" },     //5 = 015C
#endif
#ifdef FORD_T5
  { "TFT", "`C", "221674", "6", "0", "120", "3", "0", "99" }  //6 = 221674 for FORD T5
#else
  { "Trans Temp", "`C", "221E1C", "5", "0", "120", "3", "1", "99" }  //6 = 221E1C for FORD T6+
#endif

};

//barometric pressure "0133"  turbo boost = map - bp;
//hold warning value
String warningValue[7] = { "80", "99", "35", "4000", "15", "99", "99" };

/*  User configuration here to change display 
      layout 0      layout 1       layout 2     layout 3      layout 4     layout 5
    █ 1 █ █ 7 █   █ 1 █  █  █    █  █ 4 █  █   █  █  █ 7 █   █  █  █  █   █  █  █  █
    █ 2 █ █ 8 █   █ 2 █  3  4    1  █ 5 █  4   1  2  █ 8 █   1  2  3  4   1  2  3  4
    █ 3 █ █ 9 █   █ 3 █  █  █    █  █ 6 █  █   █  █  █ 9 █   █  █  █  █   █  █  █  █

set up meter here which pid to use on each cell
0 - engine load
1 - coolant
2 - manifold Pressure
3 - engine Speed
4 - pcm volt
5 - oil Temp
6 - trans Temp
*/
const uint8_t pidInCell[8][7] = {
  //[layout][cellNo]
  //the last cell must be 3 (engine speed) to check engine off
  { 0, 2, 3, 1, 5, 6, 4 },  //layout 0 -> 6 cell {load,map,engspd,coolant,oil,tft,pcmvolt
  { 0, 2, 3, 1, 5, 6, 4 },  //layout 1 -> 6 cell {load,map,engspd,coolant,oil,tft,pcmvolt
  { 0, 2, 3, 1, 5, 6, 4 },  //layout 2 -> 6 cell {load,map,engspd,coolant,oil,tft,pcmvolt
  { 1, 5, 6, 3, 2, 4, 4 },  //layout 3 -> 5 cell {cooland,oil,tft,map,pcmvolt,pcmvolt}
  { 2, 1, 5, 6, 4, 0, 4 },  //layout 4 -> 5 cell {MAP,coolant,oiltemp,tft,pcmvolt,load,pcmvolt}
  { 2, 0, 1, 5, 6, 4, 4 },  //layout 5 -> 5 cell {MAP,engload,coolant,oiltemp,tft,engload,rpm}
  { 1, 5, 6, 4, 0, 3, 4 },  //layout 6 -> 4 cell {coolant,oiltemp,tft,pcmvolt,map,endspd,pcmvolt}
  { 3, 2, 0, 4, 1, 5, 4 },  //layout 7 -> 4 cell {engspd,map,engload,pcmvolt,coolant,oil,pcmvolt}
};
// User configuration here to change display  >

/*---------------------------*/
//if NO DATA value will set to 0 to skip reading
uint8_t layout = 0;                                   //pidInCelltype 0-4 EEPROM 0x00
const uint8_t max_layout = array_length(pidInCell);   //total 5 type of display page
uint8_t pidIndex = 0;                                 //point to PID List
const uint8_t maxpidIndex = array_length(pidConfig);  //total 7 pids in picConfig
bool prompt = false;                                  //bt elm ready flag
bool skip = false;                                    //pid skip flag
uint8_t A = 0;                                        //get A
uint8_t B = 0;                                        //get B

//Global variable
const uint32_t SLEEP_DURATION = 180 * 1000000;                         //180 sec* us = 3 min
String line[12] = { "", "", "", "", "", "", "", "", "", "", "", "" };  //buffer for each line in terminal function
bool dim = false;                                                      //back light dim flag
const uint8_t LIGHT_LEVEL = 40;                                        //backlight control by light level Higher = darker light
long runtime = 0;                                                      //to check FPS
long holdtime = 0;                                                     //hold time for button pressed check
const String compile_date = __DATE__ " - " __TIME__;                   //get built date and time
bool press = false;                                                    // button press flag
bool showsystem = false;                                               //show fps and temp EEPROM 0x01
uint8_t pidRead = 0;                                                   //counter that hold number of pids been read to check pid/sec
String serial_no = "";                                                 //keep serial no.

//CPU Temp
const uint8_t tempOverheat = 60;       //max operating cpu temp 60c
const int8_t factoryTempOffset = -50;  //default offset adjustment temp up to each tested esp32 max at -50
float tempRead = 0.0;                  //current reading cpu temp
int8_t tempOffset = 0;                 //offset adjustment temp up to each tested esp32
uint8_t temp_read_delay = 0;           //hold delay counter to read temp
uint8_t temp_overheat_count = 0;       //counter to read continuiosly overheat

//BLUETOOTH
String bt_message = "";                                                     //bluetooth message buffer
String se_message = "";                                                     //serial port message buffer
String deviceName[8] = { "", "", "", "", "", "", "", "" };                  //discoveryBT name
String deviceAddr[8] = { "", "", "", "", "", "", "", "" };                  //discover BT addr
uint8_t btDeviceCount = 0;                                                  //discovered bluetooth devices counter
#define BT_DISCOVER_TIME 5000                                               //bluetooth discoery time
esp_bd_addr_t client_addr = { 0x00, 0x00, 0x00, 0x00, 0x00, 0x00 };         //obdII mac addr
esp_bd_addr_t recent_client_addr = { 0x00, 0x00, 0x00, 0x00, 0x00, 0x00 };  //keep last btaddr in RTC memory
const String client_name = "OBDII";                                         //adaptor name to search
esp_spp_sec_t sec_mask = ESP_SPP_SEC_NONE;                                  // or ESP_SPP_SEC_ENCRYPT|ESP_SPP_SEC_AUTHENTICATE to request pincode confirmation
esp_spp_role_t role = ESP_SPP_ROLE_SLAVE;                                   // or ESP_SPP_ROLE_MASTER
bool foundOBD2 = false;
BluetoothSerial BTSerial;  //bluetooth serial device

//---- Include Header File ---
#include "image.h"
#include "touchscreen.h"

/*----------- global function ---------*/

//------------------------------------------------------------------------------------------
void checkCPUTemp() {  //temperature can read only when BT or Wifi Connected
  temp_read_delay++;
  if ((temp_read_delay >= 50) && (foundOBD2)) {  //delay loop 50 then read temp, avoid error eading
    temp_read_delay = 0;
    uint8_t temperature = temprature_sens_read();      //read internal temp sensor
    tempRead = (temperature - 32) / 1.8 + tempOffset;  //change unit F to C
#ifdef SERIAL_DEBUG
    Serial.print(tempRead, 1);  //print Celsius temperature and tab
    Serial.println("°c");
#endif
    //read 10 times to confirm it's really overtemp.
    if (tempRead >= tempOverheat) temp_overheat_count++;  //count overheat time
    else temp_overheat_count = 0;                         //reset
    if (temp_overheat_count > 10) {                       //overheat read more than 10 times.
      Serial.printf("CPU Overheat Shutdown at %d°C\n", tempOverheat);
      tft.fillRectVGradient(0, 0, 320, 240, TFT_RED, TFT_BLACK);
      tft.pushImage(127, 5, 64, 64, overheat, TFT_RED);  //show sdcard icon
      tft.setTextColor(TFT_WHITE);
      tft.drawCentreString("CPU Overheat Shutdown!", 159, 75, 4);
      tft.setTextColor(TFT_WHITE, TFT_BLUE);
      tft.drawCentreString("Auto-restart within 3 minutes", 159, 140, 4);
      tft.drawCentreString("OR", 159, 170, 4);
      tft.drawCentreString("Press button to restart", 159, 200, 4);
      ledcWriteTone(buzzerChannel, 1500);
      delay(5000);
      ledcWriteTone(buzzerChannel, 0);
      BTSerial.disconnect();  //disconnect bluetooth
      tft.fillScreen(TFT_BLACK);
      tft.writecommand(0x10);  //TFT sleep
      //enter deep sleep
      esp_sleep_enable_timer_wakeup(SLEEP_DURATION);   //sleep timer 3 min
      esp_sleep_enable_ext0_wakeup(GPIO_NUM_27, LOW);  //wake when button pressed
      esp_deep_sleep_start();                          //sleep shutdown backlight auto off with esp32
    }                                                  //if temp_overheat_coun
  }                                                    //if temp_read_delay
}  //check CPU Temp
/*------------------*/
//TERMINAL terminal for debugging display text
void Terminal(String texts, uint16_t x, uint16_t y, uint16_t w, uint16_t h) {
  uint8_t max_line = round((h - y) / 16.0);
  tft.fillRect(x, y, x + w, y + h, TFT_BLACK);
  tft.setTextColor(TFT_WHITE);
  for (uint8_t i = 0; i < max_line; i++) {
    if (i <= max_line - 2) {
      line[i] = line[i + 1];
    } else {
      line[i] = texts;
    }
    tft.drawString(line[i], x, i * 20 + y, 2);
  }                 //for
  bt_message = "";  //reset bt message
}
/*------------------*/

void checkGenuine() {                          //check if genuine obd2 gauge - must flash "gauge_factory_init.ino" first
                                               //security {serialno: "V&C-OBDII-001"}
  pref.begin("security", true);                //read only
  serial_no = pref.getString("serialno", "");  //if no serial no, then empty
  Serial.print(F("Serial No: "));
  if (serial_no == "") {
    tft.setTextColor(TFT_WHITE, TFT_RED);
    tft.drawString("Not genuine Va&Cob Gauge!", 0, 115, 4);
    Serial.println(F("Not genuine Va&Cob Gauge!"));
    while (true) {  //beep
      ledcWriteTone(buzzerChannel, 2000);
      digitalWrite(LED_RED_PIN, LOW);  //red on
      delay(500);
      ledcWriteTone(buzzerChannel, 0);
      digitalWrite(LED_RED_PIN, HIGH);  //red off
      delay(500);
    }
  } else {
    Serial.println(serial_no);  //print serial no
    pref.end();
  }
}
//----------------------------------------------

//---- Include Header File --------------------
//#include "image.h"
#include "bluetooth.h"
#include "meter.h"
#include "config.h"
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
void loop() {
  //SCAN BUTON (button press HOLD to config menu)
  if (digitalRead(SELECTOR_PIN) == LOW) {  //button pressed
    if (!press) {
      press = true;                           //set flag
      holdtime = millis();                    //set timer
    } else if (holdtime - millis() > 3000) {  //press once and longer than 3 sec
      configMenu();                           //open config menu
      press = false;                          //reset flag
      if (foundOBD2) initScreen();            //open new layout screen
    }                                         //else if holdtimer > 30000
    delay(200);                               //delay avoid bounce
  } else {                                    //button release
    if (press) {                              //change layout next page
      layout++;                               //change to next layout page
      if (layout == max_layout) layout = 0;
      ledcWriteTone(buzzerChannel, 5000);  //play click sound
      delay(5);
      ledcWriteTone(buzzerChannel, 0);
      initScreen();  //open meter screen
                     //reset variable
      for (uint8_t i = 0; i < maxpidIndex - 1; i++) old_data[i] = 0.0;
      engine_off_count = 0;
      BTSerial.flush();                   //clear tx
      while (BTSerial.available() > 0) {  //clear rx buffer
        BTSerial.read();
      }
      bt_message = "";
      skip = false;
      pidIndex = maxpidIndex - 1;  //will be +1 to be 0
      press = false;               //reset flag
      prompt = true;               //to trig reading elm again
      delay(200);                  //delay avoid bounce

    }  //if press

  }  //else digitalRead
     //----------------------
     //BLUETOOTH read
  while (BTSerial.available() > 0) {
    char incomingChar = BTSerial.read();
    if (incomingChar == '>') {  //check prompt
      BTSerial.flush();         //clear tx
#ifdef SERIAL_DEBUG
      Serial.println(bt_message);
#endif
#ifdef TERMINAL  //for degbugging
      getAB(bt_message);
      Terminal(bt_message + "->" + String(A) + "," + String(B), 0, 48, 320, 191);
#endif
      prompt = true;  //pid response ready to calculate & display
    } else {
      bt_message.concat(incomingChar);  //keep elm327 respond
    }
  }
  //----------------------
  //SERIAL PORT read
  if (Serial.available() > 0) {
    char incomingChar = Serial.read();
    //check CR/NL
    if ((incomingChar != '\r') && (incomingChar != '\n')) {
      se_message.concat(incomingChar);
      //Serial.print(incomingChar,HEX);
    } else {

      if (se_message != "") {
#ifdef TERMINAL
        Terminal(se_message, 0, 48, 320, 191);  //display terminal
#endif
        BTSerial.print(se_message + "\r");
        se_message = "";
        Serial.flush();
      }  //if se_message

    }  //else if incomingChar
  }    //if Serial.available

  //Send another PID to elm327
  if (prompt) {      //> ELM327 ready! -> request next PID
    prompt = false;  //no prompt from ELM327
    checkCPUTemp();  //check temperature.
    if (!skip) {
      updateMeter(pidIndex, bt_message);  //update meter screen
      pidRead++;                          //for calculate pid/s
    }
    pidIndex++;  //point to next pid
    if (pidIndex >= maxpidIndex) {
      pidIndex = 0;  //back to pid 0
      autoDim();     //auto backlight handle
      if (showsystem) {
        String status = String(pidRead * 1000.0 / (millis() - runtime), 0) + " p/s " + String(tempRead, 1) + "`c";
        tft.setTextColor(TFT_YELLOW, TFT_BLACK);
        tft.drawCentreString(status.c_str(), 159, 0, 2);
        runtime = millis();
      }             //if showsystem
      pidRead = 0;  //reset pid read counter
    }
    if (pidCurrentSkip[pidIndex] <= 0) {                 //end of skip loop , go next index
      pidCurrentSkip[pidIndex] = pidReadSkip[pidIndex];  //read max delay loop to current
      skip = false;
      BTSerial.print(pidList[pidIndex] + "\r");                 //send PID request
    } else {                                                    //skip sending request
      pidCurrentSkip[pidIndex] = pidCurrentSkip[pidIndex] - 1;  //decrese loop count
      prompt = true;
      skip = true;
    }  //else

  }  //if prompt

  /*------------------*/
}  // loop

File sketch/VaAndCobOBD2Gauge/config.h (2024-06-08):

/* "config.h"
this header file is for configuration menu
*/
//freeRTOS multi tasking
#include <esp_task_wdt.h>
#include <freertos/FreeRTOS.h>
#include <freertos/task.h>

#include "music.h"   //songs data
#include "nes_audio.h" //nes audio player
#include "firmware_update.h" //firmware updater function
#include "elm327.h"// read VIN function

#define mypic_filename "/mypic.jpg"//mypic file
#define FORMAT_SPIFFS_IF_FAILED true//format if no spiffs


Cartridge player(BUZZER_PIN);//not specified 4 pin , use 1 pin at buzzer pin

//configuration menu 
const String menuList[8] = {
  "Show pid/s & CPU Temp",//toggle show system
  "Load my pic 320x240 px",//load user own pic
  "Update firmware",//update new firmware
  "Warning setting",//setting warning parameter (warning data, offset temp)
  "DTCs",//dtc engine 
  "Auto-off",//auto turn off
  "About",//about
  "Exit"
  }; 
const uint8_t maxMenu = array_length(menuList);//length of menu list

//menu list for warning setting
const String parameterList[8][2] = {
    {"CPU Overheat Temperature "+String(tempOverheat)+"`c ,offset "," `c  "},
    {"- Engine Load"," %  "},
    {"- Coolant Temperature"," `c  "},
    {"- Manifold Air Pressure"," psi "},
    {"- Engine Speed"," rpm "},
    {"- PCM Voltage"," volt"},
    {"- Engine Oil Temperature"," `c  "},
    {"- Transmission Fluid Temperature"," `c  "}
  };  

//increasement and decreasement of each PID  
const int pidWarnStep[8] = {1,5,1,5,500,1,1,1};

//Sprites
TFT_eSprite car = TFT_eSprite(&tft);
TFT_eSprite bk = TFT_eSprite(&tft);
TFT_eSprite pole = TFT_eSprite(&tft);
TFT_eSprite fence = TFT_eSprite(&tft);

//------ NES Audio play on Task0
TaskHandle_t TaskHandle0 = NULL;//create taskhandle0

void TaskPlayMusic(void *pvParameters) {
  esp_task_wdt_init(62, false);//62 sec wd timer / disable wd
  while(1) {
 // player.frame_counter_cb(danceLight);//cal back fucntion (not use)
  player.play_nes(song , true, 0.25); //play nes music, loop, volume 0.25, <lower vol lower distortion>
 
  }
}
//----------------------------
void animation() {//start field effect
//sprite variable
#define BK_HEIGHT 80
#define BK_WIDTH 235
  uint8_t cur_x = 68;
  uint8_t cur_y = 10;
  uint8_t dash_x = 20;
  int16_t tag_x = 235;
  int16_t fence_x = 0;
  uint8_t ani_speed = 2;

//create spirtes
  bk.createSprite(BK_WIDTH,BK_HEIGHT);

  car.createSprite(CAR_WIDTH,CAR_HEIGHT);//image size 114x50
  car.setSwapBytes(true);
  car.pushImage(0,0,CAR_WIDTH,CAR_HEIGHT,futurecar);//image size 114x50

  pole.createSprite(POLE_WIDTH,POLE_HEIGHT);
  pole.setSwapBytes(true);
  pole.pushImage(0,0,POLE_WIDTH,POLE_HEIGHT,pole1);

  fence.createSprite(FENCE_WIDTH,FENCE_HEIGHT);
  fence.setSwapBytes(true);
  fence.pushImage(0,0,FENCE_WIDTH,FENCE_HEIGHT,fence1);
//-------------------------------
  tft.fillScreen(TFT_BLACK);//clear screen  
//draw QRCode
  tft.drawBitmap(0, 159, qrcode, QRCODE_WIDTH, QRCODE_HEIGHT, TFT_WHITE);
//draw text
  tft.setTextColor(TFT_WHITE);
  tft.drawString(">MAP/ENG LOAD/ECT/EOT/TFT/ENG SPD/PCM Volt",0,40,2);
  tft.drawString(">Warning, Automatic Dim/OnOff/O็verheat Shutdown",0,60,2);
  tft.drawString(">Read DTC Code & Clear MIL Status",0,80,2);
  tft.drawString("* FW-\"VaandCobOBD2Gauge.bin\" * Image-\"mypic.jpg\"",0,100,2);
  tft.drawString("* Facebook : www.facebook.com/vaandcob",0,120,2);
  tft.setTextColor(TFT_YELLOW);
  tft.drawString("  [ Manual ] ----------------[ Press button to exit ]",0,140,2);
  tft.setTextColor(TFT_CYAN); 
  String txt = "[ "+serial_no+" ] BUILD : "+compile_date;
  tft.drawString(txt,0,0,2);
  //get VIN
  getPID("ATE0");//force echo off
  txt = "VIN :  " + getVIN(getPID("0902"));
  tft.setTextColor(TFT_GREENYELLOW); 
  tft.drawString(txt,0,20,2);

  bk.setTextColor(TFT_BLACK,TFT_ORANGE);
//loop draw Animation
  while (digitalRead(SELECTOR_PIN) == HIGH) {//exit if press button

  //draw road
    bk.fillSprite(0x4228);//draw road
    bk.fillRect(0,0,235,16,TFT_LIGHTGREY);
    bk.fillRect(0,16,235,3,0x8430);

  //draw dash line
    for(int16_t i = 0; i < 5; i++) {
                     //speed     //space //posY //length
   // bk.drawFastHLine(dash_x         +(40 * i), 20,10,TFT_WHITE);//far end dash line
      bk.drawFastHLine((dash_x-20)*1.5+(60 * i),45,15,TFT_WHITE);//middle dash line
   // bk.drawFastHLine((dash_x-40)*2.0+(80 * i),79,20,TFT_WHITE);//nearest dash line
    }
    dash_x = dash_x - ani_speed;
    if (dash_x <= 0 ) dash_x = 40;

  //draw traffic 
    tag_x = tag_x - ani_speed;
    if (tag_x <= -80) tag_x = 235;
    //bk.setTextColor(random(0xffff));
    bk.drawString("< Thank You >",tag_x,0,2);//draw billboard

  //draw car
    int8_t move = random(-1,2);
    cur_x = cur_x + move;
    move = random(-1,2);
    cur_y = cur_y + move;
    if (cur_x > 235-CAR_WIDTH) cur_x = 235-CAR_WIDTH;
    if (cur_x < 1) cur_x = 1;
    if (cur_y < 1) cur_y = 1;
    if (cur_y > 79-CAR_HEIGHT) cur_y = 79-CAR_HEIGHT;
    car.pushToSprite(&bk,cur_x,cur_y,TFT_BLACK);//put car into bk, white color as transparent
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

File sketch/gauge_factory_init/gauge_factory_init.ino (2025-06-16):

/* This is the first sketch to upload for OBDII gauge
- add serial no. by set in #define serial_no
- micro sdcard firmware upload


*/

#include <Update.h>  //
#include <FS.h>      // File System
#include <SD.h>      // SD Card ESP32
#include <Preferences.h>//save permanent data
#include <TFT_eSPI.h> //Hardware-specific library

const String serial_to_write = "V&C-001";//010


//Pin configuration
#define SCA_PIN 21//not used same pin with TFT_BL
#define SCL_PIN 22//not used (avaialable) CAN_TX
#define ADC_PIN 35//not used (available)  CAN_RX
#define LED_RED_PIN 4
#define LED_GREEN_PIN 16
#define LED_BLUE_PIN 17 
#define LDR_PIN 34    //LDR sensor
#define BUZZER_PIN 26//speaker
#define SELECTOR_PIN 27//push button
// setting PWM properties
#define backlightChannel 0
#define buzzerChannel 2

String line[12] = {"","","","","","","","","","","",""};//buffer for each line in terminal function
Preferences pref;//create preference

TFT_eSPI tft = TFT_eSPI();

//TERMINAL terminal for debugging display text
void Terminal(String texts,uint16_t x,uint16_t y,uint16_t w,uint16_t h) {
   uint8_t max_line = round((h-y)/16.0); 
   tft.fillRect(x, y,x+ w,y+ h, TFT_BLACK);
   tft.setTextColor(TFT_WHITE);
   for (uint8_t i=0;i<max_line;i++) {
     if (i<=max_line - 2) {
      line[i] = line[i+1];
     } else {
       line[i] = texts;
     } 
      tft.drawString(line[i],x,i*20+y,2);
   }//for

} 

// perform the actual update from a given stream
void performUpdate(Stream &updateSource, size_t updateSize) {
   if (Update.begin(updateSize)) {      

     //update progress
      Serial.print(F("Progress: "));
     Update //progress callback
     .onProgress([](size_t written, size_t total) {
      uint8_t progress = written * 100 / total;
      if (progress%10 == 0) {
        Serial.print(F("*"));
        Terminal("*",0,48,320,191);
      }

    }); 

      size_t written = Update.writeStream(updateSource, updateSize);
      if (written == updateSize) {
         Serial.println("Written : " + String(written) + " successfully");
      }
      else {
         Serial.println("Written only : " + String(written) + "/" + String(updateSize) + ". Retry?");
      }
      if (Update.end()) {
         Serial.println("OTA done!");
         if (Update.isFinished()) {
            Serial.println("Update successfully completed.");
            Terminal("Update successfully completed.",0,48,320,191);
            ESP.restart();
         }
         else {
            Serial.println("Update not finished? Something went wrong!");
         }
      }
      else {
         Serial.println("Error Occurred. Error #: " + String(Update.getError()));
      }

   }
   else
   {
      Serial.println("Not enough space to begin OTA");
   }
}

// check given FS for valid update.bin and perform update if available
void updateFromFS(fs::FS &fs) {
   File updateBin = fs.open("/VaAndCobOBD2Gauge.bin");
   if (updateBin) {
      if(updateBin.isDirectory()){
         Serial.println("Error, update.bin is not a file");
         updateBin.close();
         return;
      }

      size_t updateSize = updateBin.size();

      if (updateSize > 0) {
         Serial.println("Try to start update");
         performUpdate(updateBin, updateSize);
      }
      else {
         Serial.println("Error, file is empty");
      }

      updateBin.close();
    
      // whe finished remove the binary from sd card to indicate end of the process
     
   }
   else {
      Serial.println("Could not load update.bin from sd root");
   }
}
//---------------------------
void setup() {
  pinMode(SELECTOR_PIN,INPUT_PULLUP);//button
    //pwm setup
  ledcSetup(buzzerChannel, 1500, 10);//buzzer 10 bit
  ledcSetup(backlightChannel, 12000, 8);//backlight 8 bit
  ledcAttachPin(BUZZER_PIN, buzzerChannel);//attach buzzer

  Serial.begin(115200);
  delay(100);
  //init TFT display
  tft.init();
  tft.setRotation(1);//landcape 
  ledcAttachPin(TFT_BL, backlightChannel);//attach backlight
  ledcWrite(backlightChannel, 255);//full bright
  tft.fillScreen(TFT_BLACK);//show start page
  tft.drawString("Va&Cob OBDII Gauge Factory Initialize",0,0,2);
  Serial.println("Va&Cob OBDII Gauge Factory Initialize");
  Serial.println("-------------------------------------");
  Serial.print("Read Serial No: ");
  Terminal("Read Serial No: ",0,48,320,191);
//read current serial
  pref.begin("security", false);//write /read 
  String serial_no = pref.getString("serialno","");
  if (serial_no == "") {//serial no not found
    Serial.println("XXX No Serial XXX");
    Terminal("XXX No Serial XXX",0,48,320,191);
  } else {
    Serial.println(serial_no);
    Terminal(serial_no,0,48,320,191);
  }
//write a new serial no
  Serial.print("Write Serial No: ");
  Serial.println(serial_to_write);
  Terminal("Write Serial No: ",0,48,320,191);
  Terminal(serial_to_write,0,48,320,191);
  pref.putString("serialno",serial_to_write);
  pref.end();//close pref
 
  Serial.println("-------------------------------------");
  Serial.println("Insert micro sdcard with firmware \"VaAndCobOBD2Gauge.ini\"");
  Terminal("-------------------------------------",0,48,320,191);
  Terminal("Insert micro sdcard with firmware",0,48,320,191);
  Terminal("\"VaAndCobOBD2Gauge.ini\"",0,48,320,191);

  Serial.println("-------------------------------------");
  Serial.print("Press BUTTON to flash firmware");
  Terminal("-------------------------------------",0,48,320,191);
  Terminal("Press BUTTON to flash firmware",0,48,320,191);

  while (digitalRead(SELECTOR_PIN) == HIGH) {
  delay(10);
  }

   //first init and check SD card
   if (!SD.begin()) {
      Serial.println("Card Mount Failed");
   }

  uint8_t cardType = SD.cardType();

   if (cardType == CARD_NONE) {
      Serial.println("No SD_MMC card attached");
      ESP.restart();
   }else{
      updateFromFS(SD);
  }
}

//---------------------------
void loop() {
  yield();
}

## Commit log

2023-04-12 Hardware & diagram
    all hardware use and schematic diagram
2023-04-12 Add files via upload
    arduino ide board setting
2023-04-30 Update VaAndCobOBD2Gauge.ino faster pid read speed 50%
2024-08-23 Fix modified TFT_eSPI library files
    [User_Setup.h]
2024-08-23 23-August-2024 TFT_eSPI fixed
    skipped logo image to reduce flash size
    [VaAndCobOBD2Gauge.ino, config.h, meter.h]
2024-08-23 Updated on 23 August 2024
    TFT_eSPI library fixed
    Skip logo image to reduce flash size
    [VaAndCobOBD2Gauge.ino, meter.h]
2024-08-29 29 - August - 2024 Update
    - Fixed crash and reboot.
    - Fixed touchscreen
    [VaAndCobOBD2Gauge.ino]
2024-09-14 Last update Septemper 13rd ,2024
    Ford T5 , transmission fluid temperature read PID added
2024-09-27 enclosure 3d print file added
2024-09-27 Enclosure 3d print files added
    [Va&CobGauge.stl, backcover.stl]
2024-09-27 All code updated / 3d print enclosure files added
2024-09-27 Subara gauge case design by mateusleom
    Thank you
2025-02-22 3d print file
    [Va&CobGauge.3mf]
2025-03-02 necessary files for Web Flasher
    In case you don't wanna compile your own code, you can direct flash firmware into ESP32 with web flasher tool
2025-03-16 Firmware Web Flasher added
    now you can flash your CYD ESP32 from web.
    https://vaandcob.github.io/ESP32-OBD2-Gauge/sketch/firmware/webinstall.html
2025-03-16 Firmware Web Flasher implemented
    Now you can flash firmware to CYD ESP32 with webtool
2025-06-16 github commit
    [Va&CobGauge.3mf, Va&CobGauge.gcode.3mf, Va&CobGauge.skp]
